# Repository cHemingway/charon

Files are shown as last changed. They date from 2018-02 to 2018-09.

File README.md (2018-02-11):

Remake of [carrotIndustries Pluto](https://github.com/carrotIndustries/pluto) watch (see OLD_README.md) to use Cypress PSoC4208 BLE microcontroller

Not yet manufactured, use at your own risk

PSoC4 used as it is only BLE MCU I could find with Segment LCD support.

# Credits
Major thanks to Carrot Industries for reverse engineering the display and mechanicals, this project would not be possible without this.

BME680 3D model from [3D Content Central](http://www.3dcontentcentral.com/download-model.aspx?catalogid=171&id=806790)

# Changes
- MSP430 replaced with Cypress PsOC4208 BLE MCU
- Magentometer is replaced with Bosch [BME680](https://www.bosch-sensortec.com/bst/products/all_products/bme680) Temp/Pressure/Humidity/Gas sensor
- IR reciever removed
- LED polarity fixed to save GPIO

# TODO
- Manufacture
- Bring up
- Port existing Pluto firmware

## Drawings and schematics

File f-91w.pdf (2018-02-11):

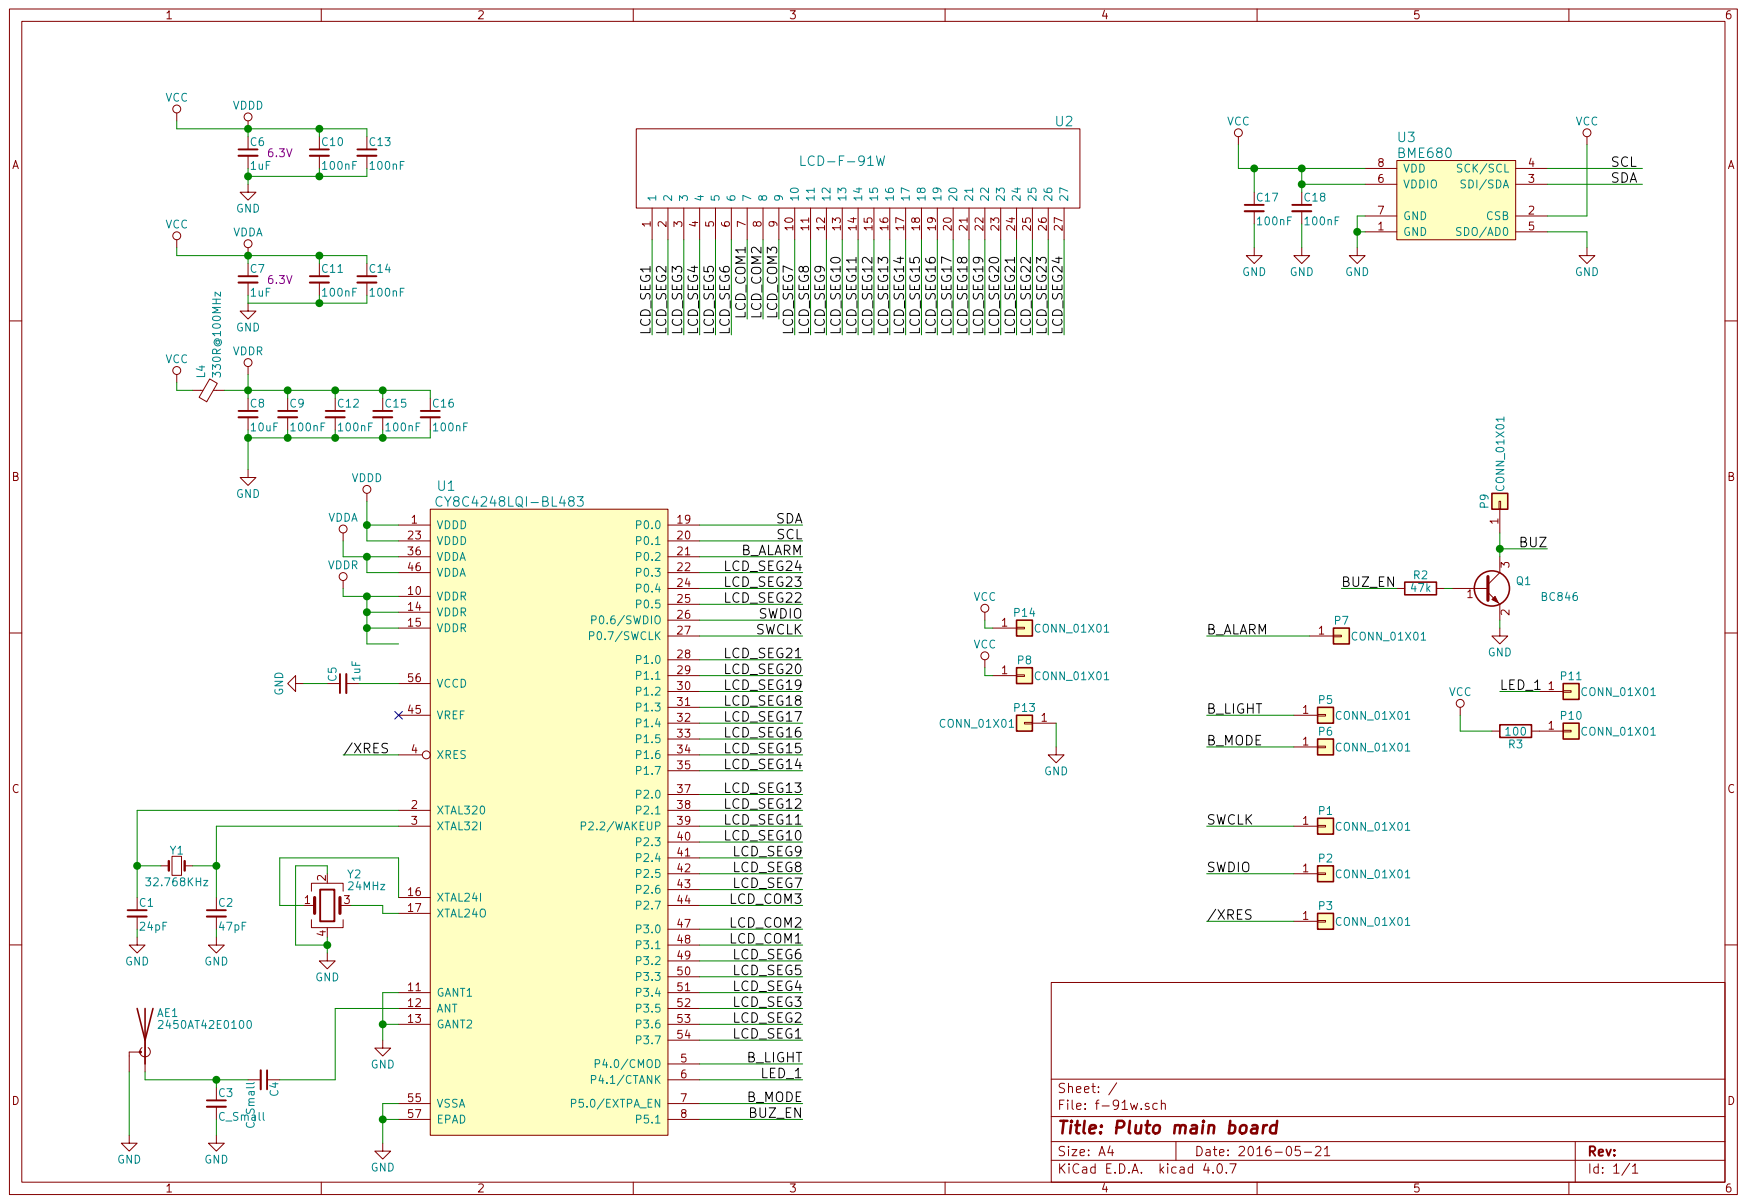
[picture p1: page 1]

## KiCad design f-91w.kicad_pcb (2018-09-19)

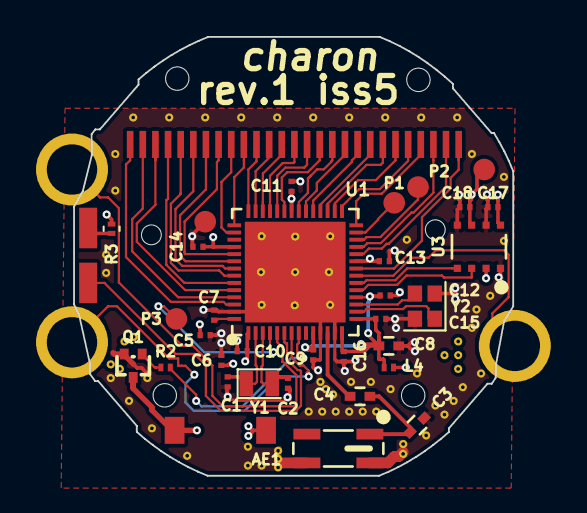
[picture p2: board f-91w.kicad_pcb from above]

Board: 4 copper layers, 24.4 x 24.4 mm, 40 parts (0 on the bottom side), 50 nets.

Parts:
AE1: 2450AT42E0100
C1: 24pF; C_0201_NoSilk
C2: 47pF; C_0201_NoSilk
C3, C4: C_Small; C_0402
C5, C6, C7: 1uF; C_0201_NoSilk
C8: 10uF; C_0402
C9, C10, C11, C12, C13, C14, C15, C16, C17, C18: 100nF; C_0201_NoSilk
L4: 330R@100MHz; R_0201_NoSilk
P1, P2, P3: CONN_01X01; TP_1.2mm
P5, P6, P7, P8, P9, P10, P11, P13, P14: CONN_01X01; 1pin
Q1: BC847BTT1; SOT416
R2: 47k; R_0201_NoSilk
R3: 100; R_0201
U1: CY8C4248LQI-BL483; Cypress_QFN56
U2: LCD-F-91W
U3: BME680
Y1: 32.768KHz; Crystal_SMD_Abracon_ABS06-2pin_2.0x1.2mm
Y2: 24MHz; Crystal_SMD_2016-4pin_2.0x1.6mm

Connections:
//XRES: P3.1, U1.4
/BUZ: P9.1, Q1.3
/BUZ_EN: R2.1, U1.8
/B_ALARM: P7.1, U1.21
/B_LIGHT: P5.1, U1.5
/B_MODE: P6.1, U1.7
/LCD_COM1: U1.48, U2.7
/LCD_COM2: U1.47, U2.8
/LCD_COM3: U1.44, U2.9
/LCD_SEG1: U1.54, U2.1
/LCD_SEG2: U1.53, U2.2
/LCD_SEG3: U1.52, U2.3
/LCD_SEG4: U1.51, U2.4
/LCD_SEG5: U1.50, U2.5
/LCD_SEG6: U1.49, U2.6
/LCD_SEG7: U1.43, U2.10
/LCD_SEG8: U1.42, U2.11
/LCD_SEG9: U1.41, U2.12
/LCD_SEG10: U1.40, U2.13
/LCD_SEG11: U1.39, U2.14
/LCD_SEG12: U1.38, U2.15
/LCD_SEG13: U1.37, U2.16
/LCD_SEG14: U1.35, U2.17
/LCD_SEG15: U1.34, U2.18
/LCD_SEG16: U1.33, U2.19
/LCD_SEG17: U1.32, U2.20
/LCD_SEG18: U1.31, U2.21
/LCD_SEG19: U1.30, U2.22
/LCD_SEG20: U1.29, U2.23
/LCD_SEG21: U1.28, U2.24
/LCD_SEG22: U1.25, U2.25
/LCD_SEG23: U1.24, U2.26
/LCD_SEG24: U1.22, U2.27
/LED_1: P11.1, U1.6
/SCL: U1.20, U3.4
/SDA: U1.19, U3.3
/SWCLK: P1.1, U1.27
/SWDIO: P2.1, U1.26
GND: AE1.2, C1.2, C2.2, C3.2, C5.1, C6.2, C7.2, C8.2, C9.2, C10.2, C11.2, C12.2, C13.2, C14.2, C15.2, C16.2, C17.2, C18.2, P13.1, Q1.2, U1.11, U1.13, U1.55, U1.57, U3.1, U3.5, U3.7, Y2.2, Y2.4
unnamed: AE1.1, C3.1, C4.2
unnamed: C1.1, U1.2, Y1.1
unnamed: C2.1, U1.3, Y1.2
unnamed: C4.1, U1.12
unnamed: C5.2, U1.56
unnamed: P10.1, R3.1
unnamed: Q1.1, R2.2
unnamed: U1.16, Y2.1
unnamed: U1.17, Y2.3
VCC: C6.1, C7.1, C10.1, C11.1, C13.1, C14.1, C17.1, C18.1, L4.1, P8.1, P14.1, R3.2, U1.1, U1.23, U1.36, U1.46, U3.2, U3.6, U3.8
VDDR: C8.1, C9.1, C12.1, C15.1, C16.1, L4.2, U1.10, U1.14, U1.15, U1.18

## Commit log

2018-01-21 Add PSOC4200BLE QFN56 schematic symbol
2018-01-21 Remove MSP430 MCU and 32KHz Crystal
    Will replace crystal for smaller version, possibly put BLE antenna in space left.
    [f-91w.sch]
2018-01-21 Add VDDD/VDDA/VDDR power symbols to library
2018-01-27 Add missing VDDR pin
2018-01-27 Add PSoC 4, decoupling and crystals
    No connection to rest of system yet
    [f-91w.sch]
2018-01-27 Add BME680 Temp/Humidity/Pressure/Gas sensor to library
2018-01-27 Add BME680 to schematic
    [f-91w.sch]
2018-01-28 Add power and decoupling for PSOC
    [f-91w.sch]
2018-01-28 Add capacitor footprints
    [f-91w.sch]
2018-01-28 Create (unfinished) QFN56 footprint
    TODO: Customise paste mask to avoid excess solder on centre pad
    [f-91w.sch]
2018-01-28 Add BME680 footprint
2018-01-28 PCB: First import to PCB. Lots of changes, move to 4 layer.
    Components in roughly right position, all existing traces ripped up.
    Lets us see how much space we have for BLE antenna, roughly 6.5x4x1.5mm
    [f-91w.kicad_pcb, f-91w.sch]
2018-01-28 Rewrite readme and delete old files for public release
    [f-91w.gbl, f-91w.gbo, f-91w.gbs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]
2018-01-28 Put in design rules for PCBCart, tidy up placement
    [f-91w.kicad_pcb]
2018-01-28 Fully connect schematic
    Tested in PSoC creator, and seems routable.
    [f-91w.sch]
2018-01-28 PCB: Route LCD display
    Some space left for debug test points, TBD
    [f-91w.kicad_pcb]
2018-01-28 More routing, add planes, crystals and decoupling caps
    [f-91w.kicad_pcb]
2018-01-28 More routing
    [f-91w.kicad_pcb]
2018-02-04 Add back in accidentally deleted mechanical holes
    [f-91w.kicad_pcb]
2018-02-04 Add Johanson 2450AT42E0100 Footprint
2018-02-04 Add Johanson 2450AT42E0100 antenna, initial placement
    TODO: Proper ground plane and 50R trace
    [f-91w.kicad_pcb, f-91w.sch]
2018-02-10 Add test points for SWD interface
    [f-91w.kicad_pcb, f-91w.sch]
2018-02-10 Reconnected traces broken by antenna placement
    [f-91w.kicad_pcb]
2018-02-10 Recede ground plane at top as per antenna requirements
    [f-91w.kicad_pcb]
2018-02-10 Add outer ground planes, keepout and stitching vias for antenna
    [f-91w.kicad_pcb]
2018-02-10 Slightly increase stiching vias around antenna
    [f-91w.kicad_pcb]
2018-02-10 Update antenna footprint to add polarity markings
    [f-91w.kicad_pcb, f-91w.sch]
2018-02-10 Remove solder paste from LCD connector, as uses zebra stripe.
    Works when hand soldering, but not if using solderpaste stencil
    [f-91w.kicad_pcb]
2018-02-10 Tidy silkscreen and gloss some tracks for demo
    [f-91w.kicad_pcb]
2018-02-10 Make antenna trace 50R coplanar to match eurocircuits stackup
    [f-91w.kicad_pcb]
2018-02-10 Fix battery connection on bottom layer and DRC errors
    [f-91w.kicad_pcb]
2018-02-10 Add ground vias in QFN centre pad
    [f-91w.kicad_pcb]
2018-02-10 REV1 ISSUE2: Fix all remaining DRC errors, check eurocircuits DFM
    [f-91w.kicad_pcb]
2018-02-11 Increase annular ring for all vias to 0.127mm
    [f-91w.kicad_pcb]
2018-02-11 Slightly tweak via spacing as per eurocircuit recommendation
    [f-91w.kicad_pcb]
2018-02-11 Remove soldermask over antenna trace
    Probably won't do much, but makes soldering network analyser easier
    [f-91w.kicad_pcb]
2018-02-11 Fix 32KHz crystal footprint for Abracon ABS06 series
    [f-91w.kicad_pcb, f-91w.sch]
2018-02-11 Add some 3D models for components
    [f-91w.kicad_pcb]
2018-02-11 Reduce solder paste coverage of QFN to ~65% for solderability
    [f-91w.kicad_pcb]
2018-02-11 Rev 1ISSUE 5: Fix final clearance
    [f-91w.kicad_pcb]
2018-02-11 RELEASE: Include all gerbers and PDF schematic, and update readme
    Now ready for production
    [f-91w-B.Paste.gbp, f-91w-B.SilkS.gbo, f-91w-F.Paste.gtp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]
2018-09-19 Update schematic and project to KiCad 5.0
    [f-91w.sch]
2018-09-19 Update PCB to KiCad 5.0
    [f-91w.kicad_pcb]
2018-09-19 Slight update to design rules for JLCPCB
    [f-91w.kicad_pcb]
2018-09-19 Change Q1 from obsolete BC846 to BC847BTT1
    [f-91w.kicad_pcb, f-91w.sch]
